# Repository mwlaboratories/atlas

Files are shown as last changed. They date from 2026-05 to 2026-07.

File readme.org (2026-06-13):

#+title: Atlas
#+options: toc:nil num:nil

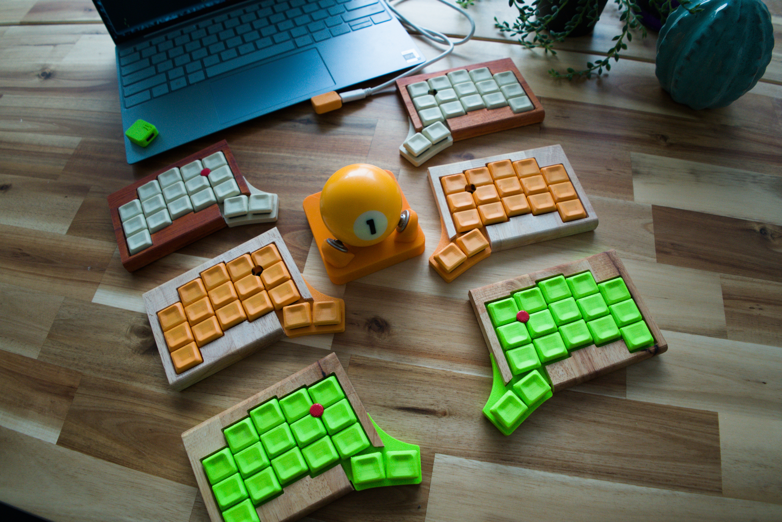
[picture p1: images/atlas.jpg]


[[file:images/keymap.svg]]

* Atlas

34-key split ergonomic keyboard with trackpoint. Per-half XIAO nRF52840
Plus, BLE split, ZMK firmware.

** Status (June 2026)

- Daily driver: breakout-board prototype, Sprintek AIO trackpoint on the
  left half. Pinned at the =proto/breakout-v1= tag.
- Next board: hand-laid KiCad PCB under =pcb/=, 34 keys (5×3
  alphas + 2 thumbs per half), Choc V2 hotswap.
- ADS1220 strain-gauge trackpoint: firmware bench-proven (HID mouse,
  radial deadzone, click-to-wake via input-processor-ping) — pinned at
  =bench/ads1220=. Currently being hand-laid into the PCB.

** Architecture

#+begin_example
Host <--BLE-- Left (central + trackpoint) <--BLE-- Right (peripheral)
#+end_example

** Mouse layer

When the trackpoint moves, the mouse layer auto-activates for ~1 s after
the last movement.

#+begin_example
Thumb keys: | SCROLL | LCLK | LCLK | RCLK |
#+end_example

** Parts

| Choc V1/V2 hotswap     | =C5333465= | Extended                                   |
| SK6812MINI-E rev-mount | =C5149201= | Extended                                   |
| 1N4148W SOD-123 diode  | =C81598=   | Basic                                      |
| XIAO nRF52840 Plus     | DNP        | Hand-solder; one per half                  |
| ADS1220 (TSSOP-16)     | =C40103=   | Strain-gauge ADC for trackpoint, integrating now |
| Sprintek SK8707-PT     | DNP        | AIO trackpoint (used in current prototype) |

** Previous work

- =proto/breakout-v1= — breakout-board prototype (daily driver). KiCad
  PCB + hand-wired XIAO breakouts.
- =bench/ads1220= — ADS1220 strain-gauge ADC firmware, bench-proven,
  not yet boarded.

** Links

- [[https://thock.mwlabs.be][thock.mwlabs.be]] — audition Choc switches:
  hear each one with a simulated typist and hot-swap on the fly.
  Background + vote for the group-buy favourite:
  [[https://mwlabs.be/lab-journal/introducing-thock/][Introducing Thock]].
- [[https://mwlabs.be][mwlabs.be]] — mwlabs.

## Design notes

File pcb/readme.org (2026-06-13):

#+title: Atlas PCB

Source files for the Atlas keyboard PCB — a hand-laid KiCad board.

* Files

| =kicad/=              | KiCad project — =keyboard.kicad_pcb= is the source of truth. |
| =parts.yaml=          | BOM — LCSC part numbers, disposition.                        |
| =parts-checklist.org= | Pre-fab checklist for JLCPCB ordering.                       |
| =keyboard.json=       | Original layout reference (KLE-style).                       |

* Workflow

=kicad/keyboard.kicad_pcb= is edited directly in KiCad.

1. Place / adjust footprints and route in KiCad.
2. Tag each footprint with its =LCSC= field from =parts.yaml=.
3. Run *Fabrication Toolkit* → upload the zip to JLCPCB.

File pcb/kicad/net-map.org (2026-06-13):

#+title: Atlas net map (XIAO ↔ matrix ↔ ADS1220)

Verified pin assignment for the hand-laid board. Each XIAO pad carries
its net directly (schematic-less; KiCad-10 name-only nets). Right half is
the same map with an =R_= prefix so the two BT halves stay electrically
separate. Source of truth: =bench/ads1220= firmware + Seeed XIAO nRF52840
Plus pinout. Independently audited 2026-06-13.

* XIAO pad → pin → net

| Pad | Pin  | nRF    | Left net | Right net | Role          |
|-----+------+--------+----------+-----------+---------------|
|   1 | D0   | P0.02  | ROW0     | R_ROW0    | matrix row    |
|   2 | D1   | P0.03  | ROW1     | R_ROW1    | matrix row    |
|   3 | D2   | P0.28  | ROW2     | R_ROW2    | matrix row    |
|   4 | D3   | P0.29  | ROW3     | R_ROW3    | thumb row     |
|   5 | D4   | P0.04  | COL0     | R_COL0    | col (pinky)   |
|   6 | D5   | P0.05  | COL1     | R_COL1    | col (ring)    |
|   9 | D8   | P1.13  | COL4     | R_COL4    | col (inner)   |
|  10 | D9   | P1.14  | COL3     | R_COL3    | col (index)   |
|  11 | D10  | P1.15  | COL2     | R_COL2    | col (middle)  |
|  12 | 3V3  | —      | 3v3      | R_3v3     | power         |
|  13 | GND  | —      | GND      | R_GND     | ground        |
|  15 | D11  | P0.15  | CS       | R_CS      | ADC chip-sel  |
|  16 | D12  | P0.19  | DRDY     | R_DRDY    | ADC data-rdy  |
|  21 | D17  | P1.03  | SCLK     | R_SCLK    | ADC SPI clk   |
|  22 | D18  | P1.05  | MISO     | R_MISO    | ADC SPI in    |
|  23 | D19  | P1.07  | MOSI     | R_MOSI    | ADC SPI out   |

Free: D6 (pad 7), D7 (pad 8) — former PS/2 trackpoint pins, now unused.

* Notes

- Thumbs fold into the main matrix: the 2 thumb keys per half sit on
  ROW3 × {COL3, COL4}. The board's old =TROW0/TCOL0/TCOL1= nets were
  renamed accordingly.
- SPI to the ADS1220 runs through series resistors R1–R4 (badjeff's
  front-end): XIAO → R → ADS1220. DRDY is a direct GPIO.
- Columns are NOT pin-mirrored between halves — both wire pinky→D4 and
  inner→D8 physically. (The firmware's reversed col-gpios list is logical
  numbering only; verified against switch X-positions.)
- Open item: which physical thumb is COL3 vs COL4 is a keymap-level
  choice, not electrical — confirm against the keymap when routing.

* Power path

LiPo → on/off slide switch (Alps SSSS811101) → XIAO BAT+.

| Node            | Net      | Pads                                   |
|-----------------+----------+----------------------------------------|
| Battery +       | VBAT     | SW pad1 (or a BAT+ solder pad)        |
| switched BAT+   | BAT_SW   | SW pad2 (common) → XIAO BAT+ (pad28)   |
| Battery − / GND | GND      | XIAO BAT− (pad29) → ground             |

- BAT+ = XIAO pad28 (nearest D6), BAT− = pad29 (nearest D7), viewed from
  the underside. Right half = R_VBAT / R_BAT_SW / R_GND.
- To verify: SW pad2 is assumed the SPDT common terminal (pad3 NC).
- No connector (JST PH too tall) — BAT+/BAT- are hand-soldered pads:
  BAT+ pad → VBAT (→ switch), BAT- pad → GND.

* Per-key RGB LEDs

17× SK6812MINI-E per half, daisy-chained. XIAO D6 (LED_DATA / R_LED_DATA)
→ first LED DIN → DOUT→DIN chain (=lednet_0..16=) → tail (NC). VCC → 3v3,
GND common.

- Chain order is a position-serpentine *default* — re-order freely while
  routing; just match the firmware LED-position map to the final order.
- Not yet placed: data-line level shifter MOSFET (3.3 V SK6812 data can
  be marginal) and the LED-power gating P-FET (=UG_EN=). Data is direct
  to D6 and VCC is ungated 3v3 for now.
- Firmware RGB is still commented out (=CONFIG_ZMK_RGB_UNDERGLOW=) — wire
  the &led_strip to D6 when enabling.

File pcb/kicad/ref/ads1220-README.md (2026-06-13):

# ADS1220 PCB

[Texas Instruments ADS1220](https://www.ti.com/product/ADS1220) ADC sensor breakout board.

- Designed for measuring wheatstone bridge circuit on Lenovo ThinkPad T440 series trackpoint sensor.
- Be operated with 3.3V voltage level ONLY.
- Unipolar Analog Power Supply ONLY.
- Outlined as small as possible for bottom mount on low profile keyboards.

## PCB

Online preview avaliable [here](https://kicanvas.org/?github=https%3A%2F%2Fgithub.com%2Fbadjeff%2Fads1220-pcb), powered by [KiCanvas](https://github.com/theacodes/kicanvas).



*Figure 2: PCB edgecuts dimension*



*Figure 3: PCB 3D View - 1.0mm FR4*

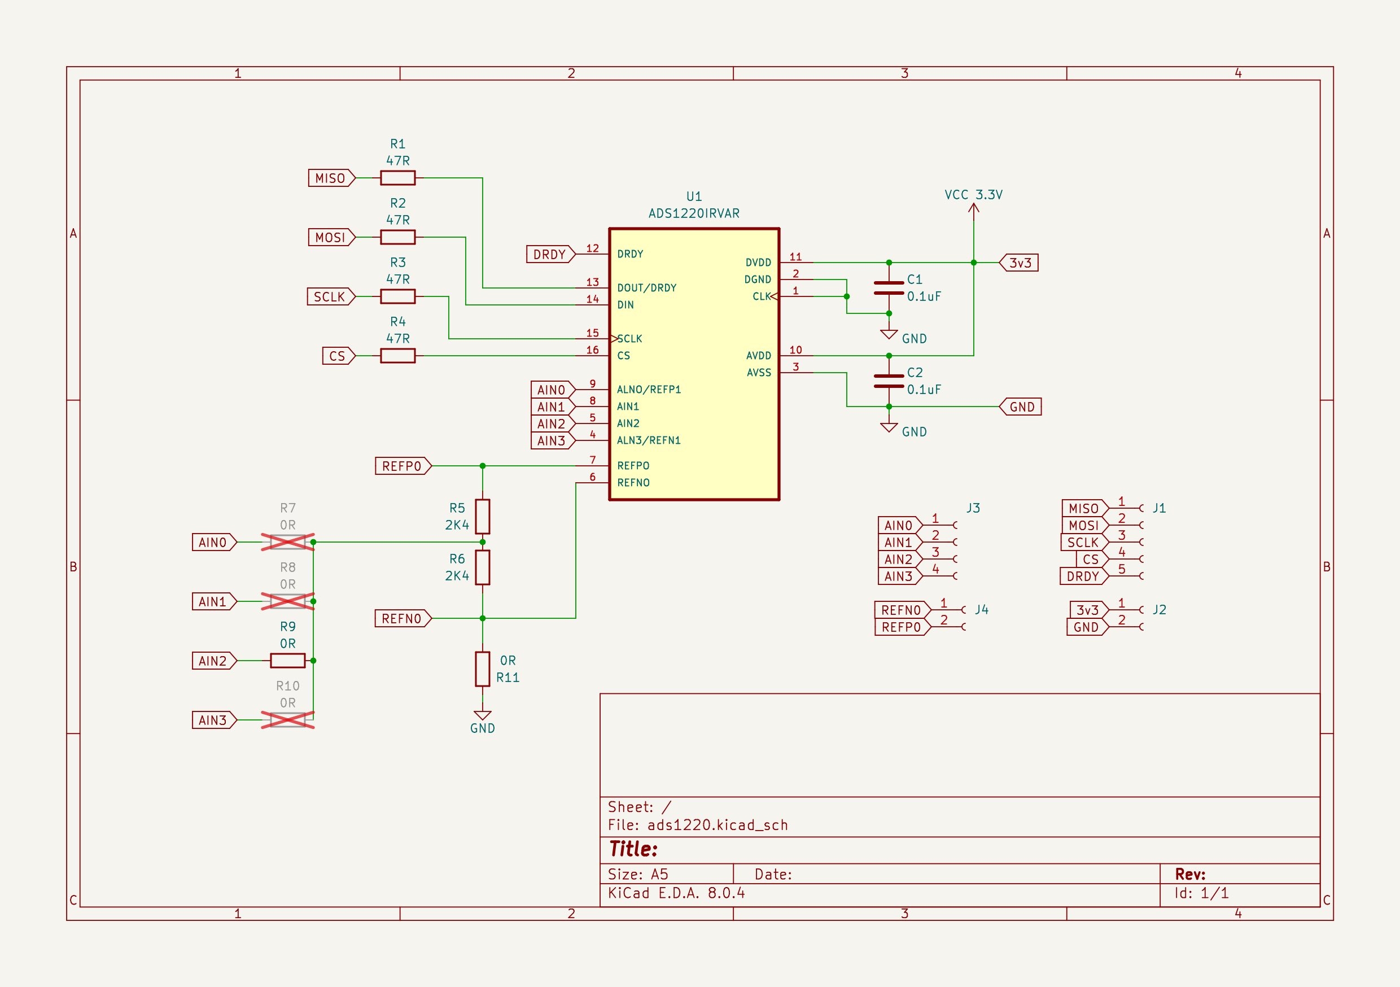
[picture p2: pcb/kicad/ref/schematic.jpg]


*Figure 4: Schematic*

### BOM

|Designator|Footprint|Quantity|Value|LCSC Part #|
|-|-|-|-|-|
|C1,C2|SMD 0402|2|100nF|C1525|
|R1,R2,R3,R4|SMD 0402|4|47R|C137973|
|R5,R6|SMD 0402|2|2K4 (for V+ Ref)|C112296|
|R7|SMD 0402|1|0R (for V- Ref)|C106231|
|U1|ADS1220IRVAR|1|VQFN-16-EP(3.5x3.5)|C2651338|
|J1|1.27mm Pin header|1|1x5|-|
|J2,J4|1.27mm Pin header|2|1x2|-|
|J3|1.27mm Pin header|1|1x4|-

- SMD 0402 (Imperial) aka 1005 Metric.

### Board Characteristics

- Copper layer count: 2
- Board thickness: 1.0 mm
- Board overall dimensions: 10.0 x 10.0 mm

## License

Available under the [CERN-OHL-P v2](/LICENSE) permissive license.

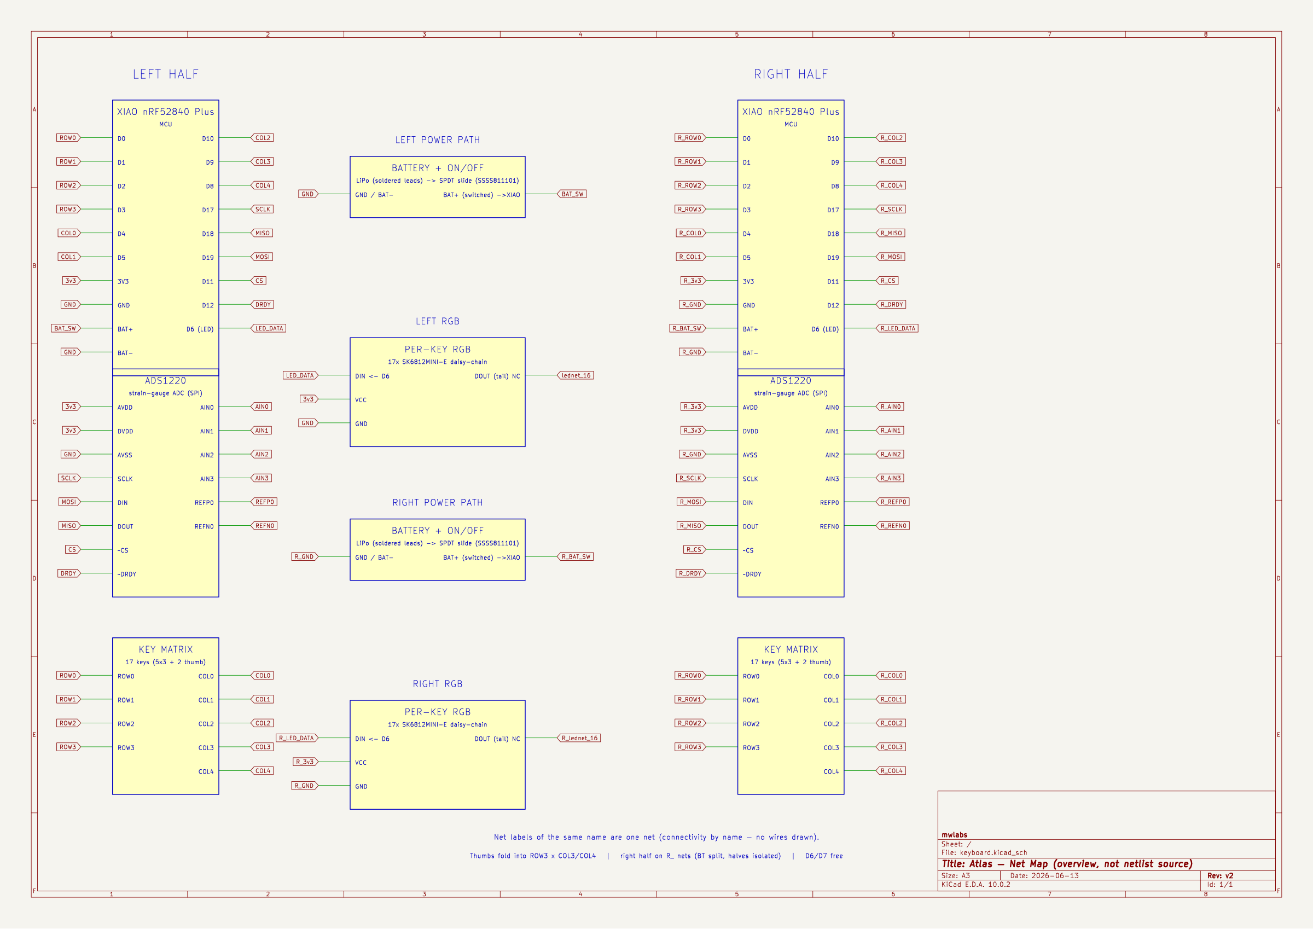
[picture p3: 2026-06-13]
pcb/kicad/net-map.png

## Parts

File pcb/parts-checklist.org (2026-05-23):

#+title: Atlas Parts Checklist — JLCPCB / LCSC lookup
#+startup: indent

Each part: what to search for, quantity per half, expected stock category,
and the LCSC code field to fill in once verified. The Atlas design uses
*BLE between halves*, so each half is independent → everything below
times two for a full keyboard.

When you verify a code, edit the =LCSC:= line and tick the checkbox.
The =parts.yaml= file alongside this one is the canonical machine-readable
source; this file is the human-friendly view to use while shopping.

* Status legend

- =Basic= — JLCPCB always-stocked, no setup fee
- =Extended= — Stocked but ~$3 setup fee per unique part
- =Pre-order= — JLCPCB orders for you, may have minimum quantity
- =Consign= — You ship them stock; not usable for standard PCBA
- =DNP= — Do Not Place; hand-solder after delivery

* Switches & matrix

** [X] Kailh Choc V1/V2 hotswap socket
- LCSC: =C5333465=
- Stock: Pre-order (min 72 pcs, ~$9 total)
- Footprint: =Switch_Keyboard_Hotswap_Kailh:SW_Hotswap_Kailh_Choc_V1V2=
- Qty per half: 17  ·  Total: 34  ·  Order 72 (38 spare)

** [ ] Matrix diode (1N4148WS)
- Search: "1N4148WS SOD-323" or "switching diode SOD-323"
- LCSC: ~C81598~ ← verify
- Stock: should be Basic
- Footprint: =Diode_SMD:D_SOD-323=
- Qty per half: 17  ·  Total: 34
- Orientation matters — JLCPCB rotation may need =+90°= correction

* RGB LEDs

** [ ] SK6812MINI-E reverse-mount
- Search: "SK6812MINI-E" — be careful, plain SK6812MINI is different
- LCSC: ~C2843680~ ← verify (this code may be wrong)
- Stock: Extended (~$3 setup)
- Footprint: =LED_SMD:LED_SK6812MINI-E_3.2x2.8mm_P1.5mm_ReverseMount=
- Qty per half: 17  ·  Total: 34

** [ ] LED decoupling cap (100 nF 0402)
- Search: "100nF 0402 X7R"
- LCSC: ~C1525~ ← verify
- Stock: Basic
- Footprint: =Capacitor_SMD:C_0402_1005Metric=
- Qty per half: 17 (one per LED)  ·  Total: 34
- Optional but standard. Skip if PCBA cost is sensitive.

* Power

** [ ] LiPo battery — choose capacity first
- Format: single-cell LiPo, ~3.7V nominal
- Capacity options: 110 mAh (compact) / 250 mAh / 400 mAh+
- Connector: JST PH 2.0 (most common) — or solder pads on the PCB
- *NOT JLCPCB part* — buy separately (Adafruit, AliExpress, etc.)
- Qty per half: 1  ·  Total: 2
- Decide capacity based on case size and battery life targets

** [ ] Battery connector (JST PH 2.0, 2-pin, SMD)
- Search: "JST PH 2.0 SMD 2-pin"
- LCSC: TBD
- Stock: usually Basic
- Footprint: =Connector_JST:JST_PH_S2B-PH-SM4-TB_1x02-1MP_P2.00mm_Horizontal= (or similar)
- Qty per half: 1  ·  Total: 2
- Skip this if you decide to solder battery wires directly to pads

** [ ] Power slide switch (SP3T or SPST)
- Suggestions:
  - C&K PCM13 (was in main-branch yaml): SP3T, allows off / XIAO / XIAO+TP modes
  - Simpler: SP DT slide switch, just on/off
- Search: "SP3T slide switch SMD" or "SPDT slide switch SMD"
- LCSC: TBD
- Stock: usually Basic or Extended
- Footprint: depends on which switch
- Qty per half: 1  ·  Total: 2

** No boost converter (decided from ZMK community guidance)
- SK6812MINI-E only needs 3.4V for logical-high — LiPo (3.0-4.2V) is enough.
- Reference: [[https://github.com/ebastler/zmk-designguide][ebastler/zmk-designguide]] (the de-facto wireless-ergo design guide).
- Trade-off: LEDs may dim near empty battery, but no extra IC needed.

** [ ] LED power-cutting MOSFETs (CRITICAL for battery life)
- Why: SK6812 quiescent draw ~1 mA per LED *even when "off"*.
  17 LEDs × 1 mA = 17 mA constant drain — 100× the BLE radio current.
- Solution: P-channel MOSFET on the LED VDD rail, gated by XIAO GPIO (=UG_EN=).
  Common topology in ebastler's guide: P-FET + N-FET pair for clean switching.
- Search: "P-channel MOSFET SOT-23" + "N-channel MOSFET SOT-23"
  - Common picks: AO3401 (P-FET), AO3400 (N-FET)
- LCSC P-FET: TBD (AO3401 is ~=C15127=) ← verify
- LCSC N-FET: TBD (AO3400 is ~=C20917=) ← verify
- Stock: Basic
- Footprint: =Package_TO_SOT_SMD:SOT-23=
- Qty per half: 2 (one P, one N)  ·  Total: 4
- Plus gate pull-up/down resistors (10 kΩ, ~2 per side)

** [ ] LED data-line level shifter MOSFET
- Why: XIAO's 3.3V data signal can be unreliable for SK6812MINI-E
  at battery voltage. Single N-FET inverts-and-shifts to VBAT level.
- Topology: N-FET with pull-up to VBAT — ZMK has a config flag for this.
- Search: same N-channel MOSFET as above (often AO3400)
- LCSC: shared with the power-cut N-FET
- Qty per half: 1  ·  Total: 2
- Plus pull-up resistor (1-2.2 kΩ)

** [ ] Bulk cap on battery rail (10 µF 0603)
- Search: "10uF 0603 X5R 6.3V"
- LCSC: ~C19702~ ← verify
- Stock: Basic
- Footprint: =Capacitor_SMD:C_0603_1608Metric=
- Qty per half: 1-2  ·  Total: 2-4

* Controller

** [ ] Seeed XIAO nRF52840 Plus
- LCSC: =C9900282874= (verified)
- Stock: *Consign only* (0 in stock)
- Disposition: =DNP= — hand-solder after delivery
- Footprint: =Seeed_XIAO:XIAO-nRF52840-Plus-SMD=
- Qty per half: 1  ·  Total: 2

* Trackpoint (strain-gauge path)

** [ ] ADS1220 — 24-bit ADC
- Search: "ADS1220 TSSOP-16"
- LCSC: ~C40103~ ← verify (TI brand stock at JLCPCB varies)
- Stock: usually Extended
- Footprint: =Package_SO:TSSOP-16_4.4x5mm_P0.65mm=
- Qty per half: 1  ·  Total: 2

** [ ] ADS1220 reference cap (1 µF 0603)
- Search: "1uF 0603 X7R"
- LCSC: TBD
- Stock: Basic
- Footprint: =Capacitor_SMD:C_0603_1608Metric=
- Qty per half: 1  ·  Total: 2

** [ ] ADS1220 decoupling cap (100 nF 0402)
- Reuse the LED cap (=C1525= same SKU)
- Qty per half: 2 (AVDD, DVDD)  ·  Total: 4

** [ ] Sprintek SK8707 strain-gauge sensor
- LCSC: *not stocked*
- Disposition: =DNP= — buy from Sprintek/Mouser, hand-solder
- Footprint: custom (4 strain-gauge pads + 2 screw holes + center stick hole)
- Qty per half: 1  ·  Total: 2

* Misc / TBD

** [ ] Mount holes / screw pads
- Decide screw size (M2 typical for ergo): hole diameter ~2.2 mm with annular ring
- No purchasable parts — just PCB features

** [ ] Status LED (optional)
- If you want a "BLE connected" or "battery low" indicator beyond per-key RGB
- Search: "LED 0603 red" / "LED 0603 green"
- LCSC: TBD if needed

** [ ] Pull-up resistors on I²C / SPI lines (if needed by trackpoint or other peripherals)
- 10 kΩ 0402 typical
- LCSC: =C25744= (10 kΩ 0402 1%) ← verify
- Footprint: =Resistor_SMD:R_0402_1005Metric=
- Qty: as many as your design needs

* Once codes are verified

Update both this file (tick the boxes) and =pcb/lib/parts.yaml= with the
final LCSC numbers. The yaml drives the BOM-tagging script; this file is
the audit trail.

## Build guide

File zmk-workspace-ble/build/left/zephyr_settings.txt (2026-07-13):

# WARNING. THIS FILE IS AUTO-GENERATED. DO NOT MODIFY!
#
# This file contains build system settings derived from your modules.
#
# Modules may be set via ZEPHYR_MODULES, ZEPHYR_EXTRA_MODULES,
# and/or the west manifest file.
#
# See the Modules guide for more information.
"DTS_ROOT":"/home/gomar/Documents/repos/atlas/zmk-workspace-ble/kb_zmk_ps2_mouse_trackpoint_driver"
"BOARD_ROOT":"/home/gomar/Documents/repos/atlas/zmk-workspace-ble/zmk-raw-hid"
"DTS_ROOT":"/home/gomar/Documents/repos/atlas/zmk-workspace-ble/modules/hal/stm32"
"DTS_ROOT":"/home/gomar/Documents/repos/atlas/zmk-workspace-ble/modules/hal/adi"
"DTS_ROOT":"/home/gomar/Documents/repos/atlas/zmk-workspace-ble/modules/hal/atmel"
"DTS_ROOT":"/home/gomar/Documents/repos/atlas/zmk-workspace-ble/modules/hal/espressif"
"DTS_ROOT":"/home/gomar/Documents/repos/atlas/zmk-workspace-ble/modules/hal/gigadevice"
"DTS_ROOT":"/home/gomar/Documents/repos/atlas/zmk-workspace-ble/modules/hal/nuvoton"
"BOARD_ROOT":"/home/gomar/Documents/repos/atlas/zmk-workspace-ble/zmk/app/module"
"DTS_ROOT":"/home/gomar/Documents/repos/atlas/zmk-workspace-ble/zmk/app/module"
"MODULE_EXT_ROOT":"/home/gomar/Documents/repos/atlas/zmk-workspace-ble/zmk/app/keymap-module"

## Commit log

2026-05-22 chore: fresh start
    Orphan branch. Old PCB/case automation + firmware reset. Will rebuild
    piece by piece and merge to main when ready.
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2026-05-23 feat(pcb): atlas PCB project — kbplacer base + LED + outline + mirror scripts
    KiCad 9 project at pcb/atlas/, scaffolded from editor.keyboard-tools.xyz
    (kbplacer) using the atlas KLE export. Includes:
    - keyboard.kicad_{pcb,pro,sch}: hand-merged plate outline, trackpoint
    holes, reverse-mount SK6812MINI-E LEDs under every switch, XIAO BLE
    Plus footprint, manually-moved diodes (off the hotswaps), and right
    half mirrored from left.
    - footprints/: kbplacer Kailh Choc hotswap library + Seeed_XIAO.
    - 3dmodels/: per-project copies of Choc V1 hotswap + XIAO STEPs so
    KiCad finds them via ${KIPRJMOD}.
    - fp-lib-table: project-local registration of both libraries.
    - keyboard.j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
    [Choc_V1_Hotswap.step, XIAO-nRF52840 v15.step, keyboard.kicad_pcb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]
2026-05-23 fix(pcb): mirror diodes by switch-local pose, not centerline
    Centerline-mirroring diodes put each right-half diode at x'=2·center−x —
    which inverts its X offset relative to its parent switch. With switches at
    rotation 180° on both halves, a left diode at switch+(+6, +4) ended up at
    switch+(−6, +4) on the right — visually the diode jumped to the opposite
    side of the switch.
    mirror_to_right.py now uses two passes:
    - centerline mirror for Edge.Cuts + free-placed footprints (MCU, etc.)
    - switch-local re-pair for diodes: anchor each left diode to its
    nearest left switch, lift to that switch's local frame, then place
    a copy at the paired right switch using the same local pos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
    [keyboard.kicad_pcb]
2026-05-23 fix(pcb): split right-half nets — atlas is BT, halves aren't wired
    kbplacer hands out a single shared matrix net list. For a wired split that's
    fine; for atlas (each half a standalone BLE peripheral) the row nets MUST
    NOT span the centerline, otherwise KiCad draws ratlines between halves and
    the netlist implies the boards are electrically joined.
    mirror_to_right.py now runs a third pass after the position fixes:
    - ROW{n} → R_ROW{n} on every right-half footprint pad
    (kbplacer already splits COL{n} per half, so columns are untouched).
    - On every right-half diode (D{n}_R), rename its anode net from the
    inherited Net-(D{n}-A) to Net-(D{n}_R-A).
    - On every right-half switch, r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
    [keyboard.kicad_pcb]
2026-05-24 pcb: nuke KiCad attempt, flatten to single pcb/ dir, reserve pcb/kicad/
    Previous attempt accumulated rotation bugs from custom pcbnew text-munging
    in atlas_pcb.py / mirror_to_right.py / add_leds.py. Switching strategy to
    kbplacer (proper KiCad plugin) + Fabrication-Toolkit for the next attempt.
    KiCad project will live in pcb/kicad/ so its many generated files don't
    pollute pcb/ alongside the layout source + BOM.
    Kept: keyboard.json (layout), parts.yaml + parts-checklist (BOM), SVGs,
    parts.yaml LCSC code updated to verified C5149201 + C81598 (diode now
    SOD-123 / 1N4148W, basic part, no fee).
    [Choc_V1_Hotswap.step, XIAO-nRF52840 v15.step, keyboard.kicad_pcb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]
2026-05-24 feat(pcb): ergogen-driven generation pipeline (smoke test passing)
    Pivot strategy: instead of hand-building schematic in KiCad GUI + running
    kbplacer, use ergogen end-to-end. One YAML config in tools/ergogen/
    produces a complete .kicad_pcb that opens in KiCad 10 and renders via
    kicad-cli for fast visual iteration.
    Smoke test stage — single key (switch + diode + LED) generated and
    rendered successfully (see tools/renders/smoke-test-top.png).
    Toolchain:
    - nodejs_22 + ergogen 4.2.1 via npm (package.json)
    - ceoloide/ergogen-footprints vendored in tools/ergogen/footprints/ for
    Kailh Choc V1V2 hotswap, SK6812MINI-E reverse-mount, SOD-123 diode
    - pcbs.template: kicad8 (version 20240108, KiCad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
    [keyboard.kicad_pcb]
2026-05-24 feat(tools): webtool drives ergogen → KiCad → render pipeline
    Major milestone: layout webtool now has a 'build PCB' button that
    generates a KiCad PCB end-to-end from the atlas layout state.
    Pipeline:
    webtool state → POST /api/build → server.mjs
    → layoutToErgogen() → ergogen YAML
    → ergogen.process() → KiCad 8 .kicad_pcb
    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
    [keyboard.kicad_pcb]
2026-05-24 chore(devenv): server moved to process-compose, scripts kept for one-shots
    devenv has full process management (process-compose under the hood) — use
    `devenv up` to start the long-running webtool server, supervised with
    auto-restart. One-shot commands stay as scripts: `devenv shell -- ergogen`
    runs the static config build, `devenv shell -- render` renders the current
    PCB to PNGs.
    Removed standalone `dev` script (replaced by `processes.server`).
    [keyboard.kicad_pcb]
2026-05-24 docs: rewrite readme as session-handoff recap
    Captures current state (ergogen pipeline working end-to-end), the two
    abandoned approaches (KiCad pcbnew scripts, EasyEDA Pro pivot) with
    lessons, the parts table with verified LCSC codes, conventions, and
    the running TODO list. Last section is an explicit "for a fresh Claude
    session" pointer so resuming the work doesn't relitigate decisions.
2026-05-25 feat(pcb): atlas PCB from ergogen webtool pipeline; tools/ goes private
    Drops the staged ergogen + webtool tooling out of the public branch
    (tools/ is gitignored from here on) and commits only the generated
    KiCad PCB plus supporting BOM/docs. The .kicad_pcb is the totem-choc
    output of the cap-configurator pipeline — keys-only board, mirrored
    halves, trackpoint cutout between the top-right key cluster, no MCU
    (placed by hand in KiCad).
    - .gitignore: tools/ + devenv state private; keep KiCad/output cruft
    out of git (kicad_prl, autosaves, generated step/dxf/stl, gerbers,
    Fab-Toolkit zips, IDE/OS noise)
    - pcb/keyboard.svg, keyboard-outline.svg, keyboard-plate.svg removed
    (pre-pipeline r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
    [keyboard.kicad_pcb]
2026-06-04 pcb: regenerate keyboard.kicad_pcb from ergogen pipeline
    Net topology collapsed/renumbered by the latest pipeline run; no
    schematic changes intended.
    [keyboard.kicad_pcb]
2026-06-04 docs(readme): image + keymap + status, drop build-tooling section
    Brings back the photo and keymap visual from proto/breakout-v1, replaces
    the long pipeline/devenv writeup with a brief Atlas description, current
    status, mouse-layer summary, parts table, and pointers to the
    proto/breakout-v1 and bench/ads1220 tags.
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2026-06-09 pcb: rebuild board (custom outline, 3u half-gap) + hand-place XIAO BLE Plus
    Board regenerated from the layout tool with the hand-drawn outline and a
    3-unit center-to-center gap between the halves' inner columns, then the
    XIAO BLE Plus MCUs placed by hand (footprints embedded in the board, so
    the project loads standalone). Adds the KiCad project file.
    [keyboard.kicad_pcb]
2026-06-09 pcb: add 3D models to diodes, LEDs, hotswaps, and switches
    Inject (model ...) refs into the diode/LED/hotswap/switch footprints using
    the layout pipeline's calibrated offsets+rotations, so the board renders
    fully in KiCad's 3D viewer. Models live under tools/3d-models (private), so
    they resolve locally; pads/routing unchanged. XIAO instances untouched.
    [keyboard.kicad_pcb]
2026-06-09 pcb: place power switches (Alps SSSS811101) on the board
    Hand-placed the SMD side power switch (LCSC C109335) per half, with its
    3D model oriented to match the back-side mount.
    [keyboard.kicad_pcb]
2026-06-10 pcb: track project footprint library (atlas.pretty + fp-lib-table)
    The XIAO BLE Plus and Alps power-switch footprints the board already
    references were left untracked. Commit them so the board is complete and
    the atlas lib resolves on a fresh clone.
2026-06-10 pcb: fix hotswap socket 3D model depth (offset Z 0 -> 1)
    The Kailh hotswap socket STEP (CONN-SMD_HOTPLUGPAKAGE C9900010116) was
    attached at Z offset 0, sinking the socket body ~1 mm into the PCB in the
    3D view. The model's origin sits ~1.85 mm into +Z, so it needs a +1 mm
    push to sit flush against the back copper. Applied to all 34 switch
    instances.
    KiCad 10 also reserialized the whole file on save; the only geometry
    delta is the 34 socket offsets.
    [keyboard.kicad_pcb]
2026-06-13 pcb: integrate ADS1220 ADC front-end (badjeff reference)
    Vendor badjeff/ads1220-pcb (CERN-OHL-P v2) into the board:
    - add ads1220.pretty footprint lib (ADS1220 VQFN-16 + 3D model),
    registered in fp-lib-table; bake the .step model path into the
    footprint so it renders without per-instance setup
    - append the ADS1220 front-end (U1 + RC network + decoupling) onto
    the board; through-hole breakout headers removed (routes direct
    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
    [ads1220.kicad_pcb, ads1220.kicad_sch, keyboard.kicad_pcb]
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2026-06-13 pcb: vendor component 3D models into pcb/kicad/3d-models
    Move the diode/hotswap/switch/LED/XIAO/power-switch 3D models out of
    the gitignored tools/ workspace and into the tracked board so the PCB
    is self-contained — a fresh clone renders without a fetch step.
    - relocate the 6 referenced .3dshapes dirs to pcb/kicad/3d-models/
    - repoint all 140 model paths: ../../tools/3d-models -> 3d-models
    - fetch-3d-models now writes there and is a refresh helper, not setup
    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
    [keyboard.kicad_pcb]
2026-06-13 pcb: assign matrix + power + ADC nets to both XIAOs
    The MCU pads were unconnected (no nets), so routing had no targets.
    Assign every XIAO pad its net from the verified pin map (firmware
    matrix + Seeed XIAO Plus pinout):
    - rows D0-D3, cols D4/D5/D8/D9/D10, 3v3/GND
    - ADC SPI on the Plus secondary pins: CS=D11, DRDY=D12, SCLK=D17,
    MISO=D18, MOSI=D19
    - thumbs folded into the matrix (TROW0->ROW3, TCOL0/1->COL3/4)
    - right half split onto R_-prefixed nets so airwires don't cross the
    BT split; right columns mirrored (reversed) per the firmware
    Verified: 16 nets per XIAO, no net crosses the L/R split, file loads
    clean in kicad-cli.
    [keyboard.kicad_pcb]
2026-06-13 pcb: fix reversed right-half column mapping
    Verified against switch x-positions: both halves wire pinky=COL0=D4
    and inner=COL4=D8 physically (the firmware's left/right col-gpios
    reversal is logical numbering only). Right XIAO columns now map
    identically to left (pad5->R_COL0 .. pad9->R_COL4), not mirrored.
    [keyboard.kicad_pcb]
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2026-06-13 pcb: add net-map schematic (overview of XIAO/matrix/ADS1220 nets)
    A documentation schematic (openable in KiCad, PNG for quick view) that
    draws the verified net map as labeled blocks per half — MCU, ADC, and
    matrix, connectivity by net-label name. Companion to net-map.org. Not a
    netlist source; the board stays schematic-less.
    [net-map.kicad_sch]
2026-06-13 pcb: make net-map the project schematic (keyboard.kicad_sch)
    Rename net-map.kicad_sch -> keyboard.kicad_sch so it opens inside
    keyboard.kicad_pro as the project's schematic (KiCad auto-associates by
    filename; reference project confirms sheets:[] is fine). Refresh the
    viewable render at pcb/kicad/net-map.png. Title marks it an overview,
    not a netlist source — the board stays schematic-less.
    [keyboard.kicad_sch]
2026-06-13 pcb(sch): add battery + on/off switch power path to net-map
    Show the LiPo -> SPDT on/off slide (SSSS811101) -> XIAO BAT+ path per
    half, and the XIAO BAT+/BAT- pins (the middle footprint pads). BAT-/GND
    common; right half on R_ nets. Connectivity by net-label name.
    [keyboard.kicad_sch]
2026-06-13 pcb: net the power path (battery -> on/off switch -> XIAO BAT+)
    Per the user's polarity (BAT+ = pad28 near D6, BAT- = pad29 near D7):
    - XIAO pad28 -> BAT_SW (switched battery+), pad29 -> GND
    - power switch pad2 (common) -> BAT_SW (trace to XIAO BAT+),
    pad1 -> VBAT (LiPo+ lead lands here), pad3 NC
    - right half R_-prefixed
    Assumption to verify: SW pad2 = the SPDT common terminal. No JST
    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
    [keyboard.kicad_pcb]
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2026-06-13 pcb: battery uses soldered leads, not JST (update sch + doc)
    [keyboard.kicad_sch]
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2026-06-13 pcb: add battery-lead solder pads (BAT+/BAT-) footprint + place per half
    2-pad footprint for hand-soldered LiPo leads (no JST — saves height).
    Placed below the board, netted VBAT/GND (R_ on right); drag into position.
    [keyboard.kicad_pcb]
2026-06-13 pcb: net the per-key RGB LED chain (SK6812) + connect to XIAO D6
    The 34 LEDs had unchained per-key din/dout stubs and no MCU link. Link
    each half's 17 LEDs into a position-serpentine daisy-chain (DOUT->next
    DIN), drive the head from XIAO D6 (LED_DATA / R_LED_DATA), tie VCC->3v3.
    Verified: continuous chain, head reaches the XIAO, no VCC remnants.
    Note: data is direct to D6 (no level shifter), VCC ungated (no P-FET),
    firmware RGB still commented out; chain order is a routable default.
    [keyboard.kicad_pcb]
2026-06-13 pcb(sch): add per-key RGB LED chain to net-map (XIAO D6 -> SK6812 x17)
    [keyboard.kicad_sch]
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2026-06-13 pcb: net the placed battery-lead pads (VBAT/GND) -> closes power path
    [keyboard.kicad_pcb]
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2026-07-07 build: add keymap-drawer generator as a devenv script
    The generator that produces images/keymap.svg (the layer diagram in
    readme.org) was dropped from main when the build-tooling section was removed
    (d13c8de); recovered from the deleted ble-no-dongle branch.
    - nix/keymap-drawer.nix + tree-sitter-devicetree.nix: package keymap-drawer
    0.22.1 (pins tree-sitter 0.24.0 + a devicetree grammar).
    - devenv.nix: add keymap-drawer to packages + a `draw-keymap` script (named to
    avoid shadowing keymap-drawer's own `keymap` console script) that parses
    zmk-workspace-ble/config/atlas.keymap and writes images/keymap.svg. Fits the
    existing render / fetch-3d-models script pattern.
    - No justfile: firmw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
2026-10-20 Restructure repo: case STEP files, hotswap KiCad project, firmware
    - cad/: STEP per half for the wooden housing, switch plate and bottom plate.
    - pcb/: the hotswap board as ordered (atlas-left/right/panel), 3D models
    vendored under pcb/3d-models with project-relative paths. Trackpoint J1
    pinout verified on the real stick: left far->near b, a, y, x; right
    reversed. The old 19.05 mm board and its docs are removed (in history).
    - firmware/: atlas20 (ZMK shield for the new PCB, draft) and prototype-ble
    (current breakout prototype; the committed build/ output is untracked).
    - readme: repository layout, trackpoint wiring, parts per half.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
2026-10-21 firmware: prototype-ble -> ble, buildable west workspace
    Make room for a separate ESB variant next to it: firmware/ble is the
    BLE split (left = central with the strata reporter, right = peripheral,
    no dongle). The build script now runs west init on a fresh checkout;
    after the restructure the old workspace was left behind and the build
    failed with no west workspace.
    Built and flashed 2026-10-21 with zmk-strata 7ff01b0: strata gets layer,
    battery (both halves) and link frames over BLE.
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2026-11-05 pcb: drop XIAO hand-solder slots, make underside pads factory-solderable
    The board as quoted had two milled slots under each XIAO nRF52840 for
    hand-soldering its underside pads, so reflow could not connect VBAT/RST.
    Per XIAO (U1, U101; left, right and panel):
    - remove the 16 Edge.Cuts slot segments under the module
    - underside pads 17/18/20/28: 1.016 mm PTH -> SMD, placed to Seeed's
    official XIAO-nRF52840-SMD footprint (OPL_Kicad_Library)
    17 EN/RST circle 1.7 mm keeps RST
    28 VBAT rrect 1.1x1.5 mm keeps BAT_SW
    18, 20 GND mechanical lands, no net (module GND via edge pad 13)
    VBAT/GND lands shortened from Seeed's 2.5 mm to 1.5 mm: at full length
    the right-half VBAT p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
2026-11-05 repo: kicad-mcp devenv script, drop .envrc, ignore fab packages
    - devenv: kicad-mcp script (kicad-mcp-pro via uvx, libstdc++ fix for
    NixOS) + .mcp.json so Claude Code gets the KiCad MCP in this repo
    - drop .envrc: devenv auto-activates via the shell hook, no direnv
    - .gitignore: keep BOM/CPL/gerber zips out; the board is shared as
    KiCad source, assembled boards are ordered through PCBWay
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2026-11-07 pcb v4.1: move vias out of SMD pads with paste
    PCBWay CAM review (order W1126074AS6C5) flagged vias inside SMD pads with
    paste, including the XIAO edge pads. This fixes the design instead of
    relying on via-in-pad fill.
    Every via whose drill hits an SMD pad with paste now sits beside it,
    same net and size (0.60/0.30), with a short fanout stub.
    - left: 53 -> 0. Includes U1 pads 3,4,5,6,10,11,12,13. R3.1 SCLK is
    rerouted on B.Cu, which drops a 2-via F.Cu detour.
    - right: 45 -> 0. Includes U1 pads 4,5,13. R11 is shifted (-0.10,-0.35) mm
    to free a site for its pad-2 GND via.
    - panel: 98 -> 0. Replicated from the final half boards and verified to
    match each half exactly.
    Battery: BT1/BT101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
2026-11-07 pcb v4.1: add left/right board STEP exports for Fusion
    Exported from the restored-pad board state (no JST) so the halves
    can be imported into the housing design. Includes the board body and
    the 3D models that resolve on this tree (XIAO, hotswap sockets,
    diodes, ADS1220, 0402s, SOT-23, power/reset switches).
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2026-11-08 cad: rule-based case with fit checks, web viewer, print files, cached parallel builds
    Bottom plate, switch plate and housing are generated from the boards by rule
    (0.2 mm fit gaps, 0.4 mm floors on a 0.2 mm layer grid, 1.2 mm minimum feature,
    walls under the limit opened smoothly), with:
    - checks.py: 28 fit checks per half (valid single solid, overlaps, component
    and switch-leg clearance, lip lock gap, screws, floors, thin walls, clean
    geometry); `cad` fails loudly on any of them
    - thumb lip lock moved to the middle of the thumb arc, clear of all underside
    parts, with smooth run-outs; bottom plate relief tapered at its ends
    - socket pockets cut through the plate (hotswap outline only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
2026-11-08 firmware/esb: ESB split with a USB dongle, strata battery to the host
    New workspace next to firmware/ble: both halves are ESB (Enhanced
    ShockBurst) peripherals of a keyless XIAO dongle, the central, which runs
    the keymap and talks USB HID. Tracks the latest of each module: zmk main
    (Zephyr 4.1), badjeff's zmk-feature-split-esb main (RF channel hopping,
    retry fixes), his patched NCS 3.1, plus zmk-raw-hid + zmk-strata.
    - old_prototype (breakout PCB): ported from the January ESB build
    (zmk-workspace/ at 29ecb3f) without PS/2 or the trackball peripheral;
    keymap copied from firmware/ble with the &bt/&out row set to &none.
    - atlas (v4.x PCB): same split, ADS1220 pointing behind ADS1220=1, whi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
2026-11-08 cad: viewer pads/both halves/GPU check, sharp thumb ear
    - viewer: copper pads layer (kicad-cli pads-only export, viewer only, kept out
    of the fit checks), "Both" halves side by side, side panel hidden by default,
    WebGL renderer shown in the header (software fallback flagged), per-second
    perf log, errors surfaced instead of silent stops, no text selection while
    dragging, half resolution while the camera moves, lighter meshes
    - switch plate: the thumb ear runs out to its sharp point again (as drawn;
    min_feature 0 by default), accepted in the thin-wall check
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2026-11-08 cad: bottom plate pockets on a shapely polygon base
    The bottom plate's 2D pocket logic (floor levels, thin walls opened, necks,
    corner rounding, minimum feature, ledges) now runs on shapely/GEOS polygons
    on a fixed 1e-4 mm grid (geom2d.py) and goes back to OCC once: outlines noded
    together, fitted to lines and arcs per chain, extruded per level, one cut.
    The OCC-curve morphology and its repair code are gone from geom.py.
    - socket through hole = the pocket across the plastic body only (as printed),
    floor kept under the terminal tabs; joined cuts rounded r = min_feature;
    no added nubs; rounding crosses deeper walls at ~30 deg (no crescents)
    - both halves: 28/28 fit checks, 0 non-manifold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
2026-11-09 case: plate floor fix, tray roof groove, viewer updates after builds; pcb: diodes out of the trackpoint slot
    - bottom plate: pocket floors drawn for the thicker plate keep floor_skin
    instead of cutting through (the battery bay lost its floor at -5.95)
    - housing: 9.5 mm groove in the battery tray roof, 0.25 mm deeper, centred
    on the tray opening, for the thickest part of the pouch
    - viewer: loads a new build only once the server reports it finished
    - pcb (unrouted, to be rerouted): left D6 2.15 mm toward the front edge;
    right D5 5.7 mm right / 1.8 mm back out of the J1 slot; right D9 2.0 mm
    toward the front edge
    Both halves 28/28; print STLs 0 non-manifold edges.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
2026-11-09 case: tray lip into the front wall, deeper roof groove; viewer copper layers; pcb: via cleanups
    - housing: 1.6 mm lip into the front wall for the pouch (notch_y -20.2 -> -21.8,
    flush tray printed tight), lip corners at the 1/8" end mill radius; roof groove
    0.25 -> 0.75 mm deep, position settable via tray_groove_y
    - viewer: export tracks and vias as well as pads, split into cutop/cubot layers
    - pcb: small via moves on left (P3) and right (RST, K3), SCLK route simplified;
    panel regenerated. This is the board state the v4.2 PCBWay package was made from.
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2026-11-12 firmware/esb: in-order key delivery, no stuck mods or doubled keys
    zmk-feature-split-esb's app-level retry re-queues a failed key event
    behind newer ones and re-sends it as a fresh packet: a press can land
    after its release (a GUI stuck 78 s) and an ACK-lost press arrives
    twice (dongle auto-heal: release+press 1.0 ms apart, a doubled key).
    Not battery related: seen with both halves at 65 %.
    Turn off channel hopping and the key retry together (hopping relies on
    the retries to wrap back to the dongle's channel) and lean on the
    radio's own retransmits, in order and deduplicated in hardware: 15 x
    600 us, about 9 ms worst case. On the old prototype, a 3-min evdev
    capture went from 1 stuck key +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
